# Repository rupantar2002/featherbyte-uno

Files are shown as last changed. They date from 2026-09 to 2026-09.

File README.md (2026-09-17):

<div align="center">
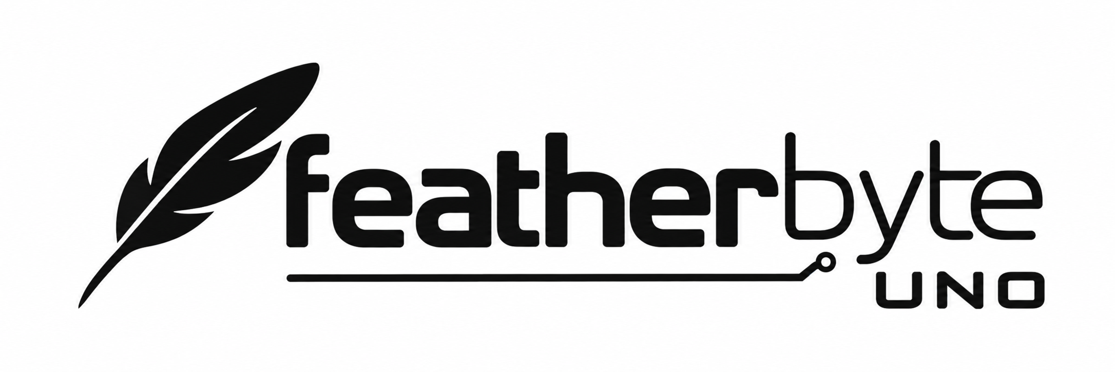
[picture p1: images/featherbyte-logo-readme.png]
Featherbyte Uno logo
  

  # Featherbyte Uno

  **A RISC-V development board in the Arduino Uno footprint.**

  USB-C • Arduino-compatible headers • CAN • Open hardware

  [Hardware](#hardware) · [References](#reference-documents) · [Getting started](#getting-started) · [Manufacturing](#manufacturing) · [Project status](#project-status)
</div>

<p align="center">
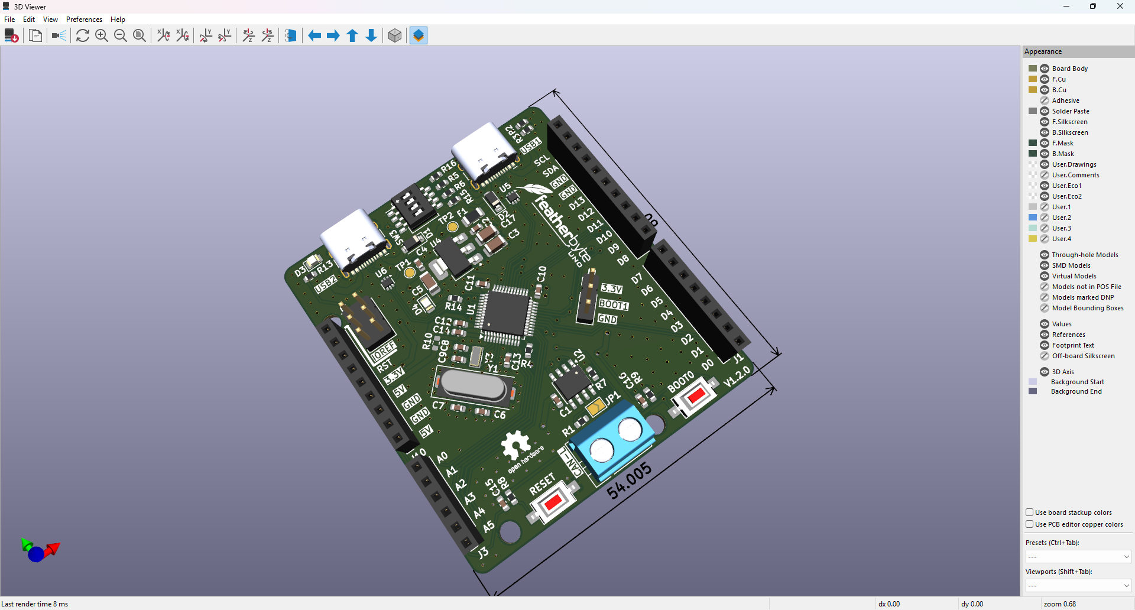
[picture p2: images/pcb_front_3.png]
Featherbyte Uno front 3D render
  
</p>

Featherbyte Uno brings the WCH **CH32V203** RISC-V microcontroller to the familiar Arduino Uno form factor. It is designed for projects that want the practical shield ecosystem, generous headers, modern USB-C connectivity, and a hardware CAN interface in one open, inspectable board design.

> [!WARNING]
> This is an active hardware project, not yet a production-qualified board. Review the design files and validate the board for your use case before ordering or deploying hardware.

## Capabilities

| | Featherbyte Uno provides |
| --- | --- |
| **Compute** | WCH CH32V203CxT6, a 32-bit RISC-V MCU based on WCH's QingKe V4B core |
| **Form factor** | Arduino Uno–compatible header layout, board outline, and mounting pattern |
| **USB** | Two USB-C receptacles: a USB device/power-input connection and a USB host + device/power-input connection |
| **Field bus** | On-board TJA1050 high-speed CAN transceiver with a screw terminal for CANH/CANL |
| **Debug** | Dedicated SWD programming/debug header |
| **Boot control** | BOOT0 push button and BOOT1 selection jumper |
| **Power & protection** | 5 V and 3.3 V header rails, USB protection, and labelled power connections |
| **Design source** | Native KiCad schematic, PCB, symbols, footprints, 3D models, and Gerbers |

## Hardware

<p align="center">
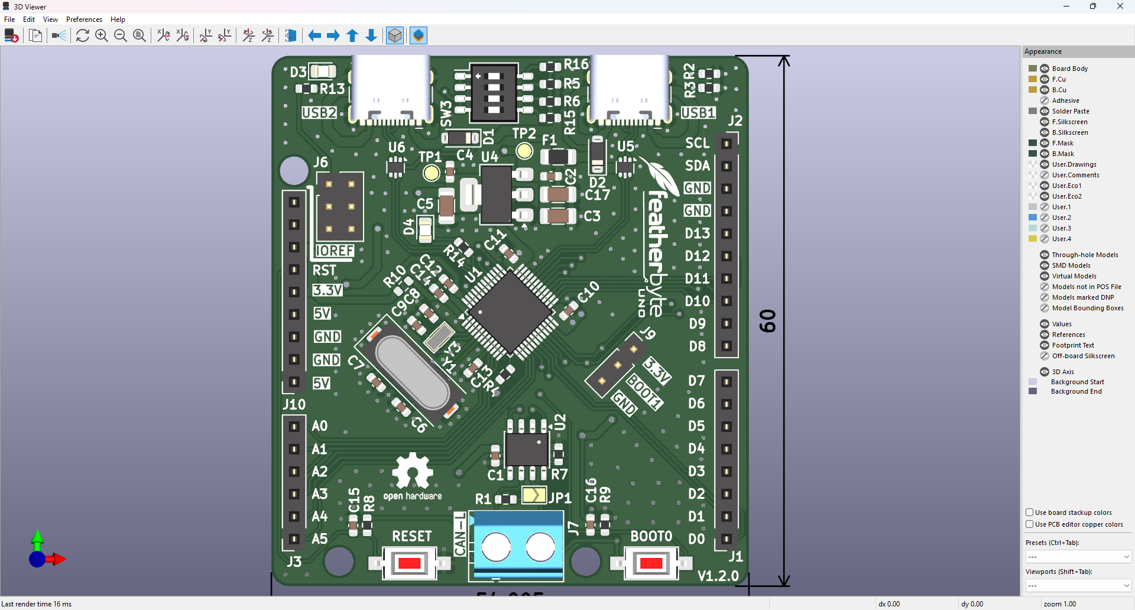
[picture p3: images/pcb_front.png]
Featherbyte Uno top-side board render
  
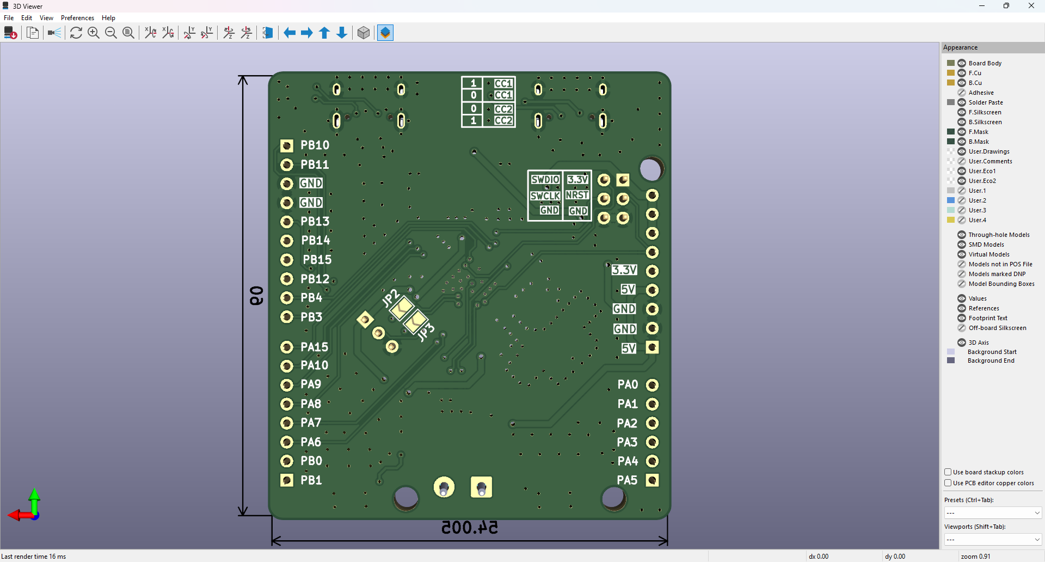
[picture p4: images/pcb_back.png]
Featherbyte Uno bottom-side board render
  
</p>

The board preserves the recognizable Uno layout while exposing CH32V203 GPIO on the standard-style digital and analog header positions. The front side carries both USB-C connections, the MCU, boot/reset controls, CAN terminal, and the Arduino-compatible headers. The reverse side provides a clearly labelled SWD header and additional breakout access.

### Key interfaces

| Interface | What it is for |
| --- | --- |
| **USB1 / USB-C device** | Device-mode connection and power input |
| **USB2 / USB-C host + device** | USB host/device connection and power input |
| **CAN** | High-speed CAN through the TJA1050 transceiver and CANH/CANL terminal |
| **SWD** | SWDIO, SWCLK, NRST, 3.3 V, and GND for programming and debugging |
| **Arduino headers** | Digital, analog, power, I²C, and SPI-style expansion in the Uno form factor |

<p align="center">
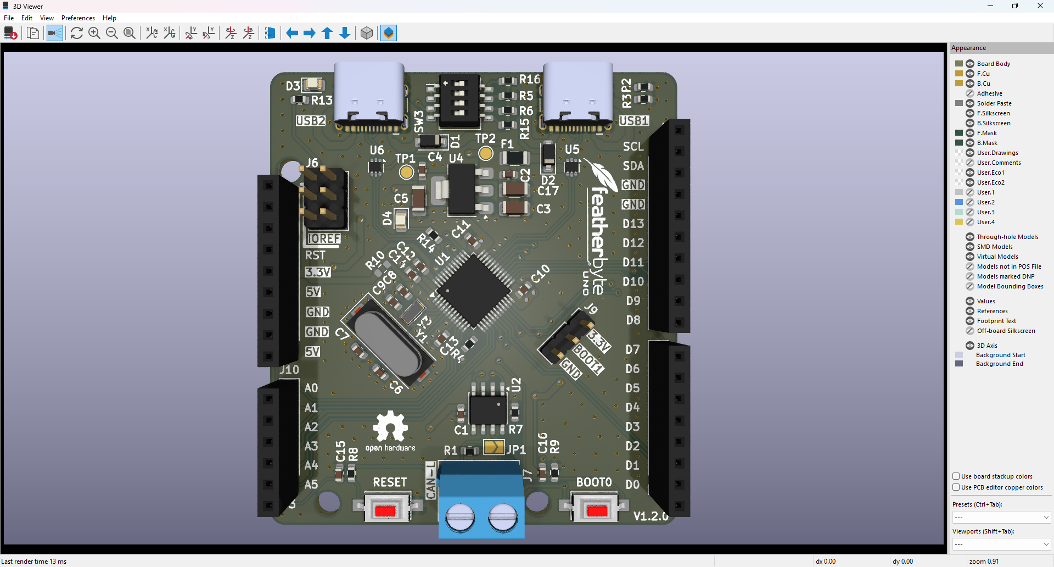
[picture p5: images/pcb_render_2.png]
Featherbyte Uno rear 3D render showing SWD breakout
  
</p>

## Hardware validation

<p align="center">
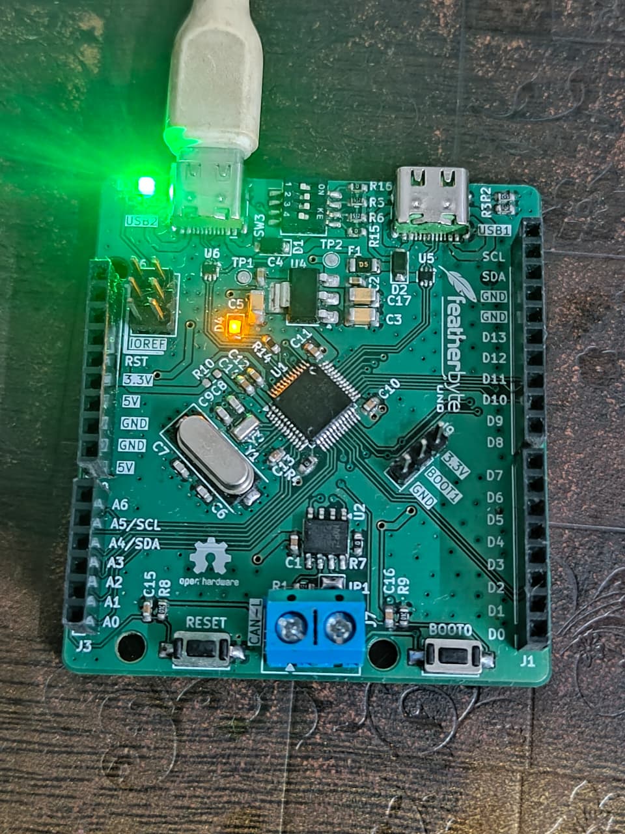
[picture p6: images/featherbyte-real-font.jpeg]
Assembled Featherbyte Uno prototype powered over USB
  
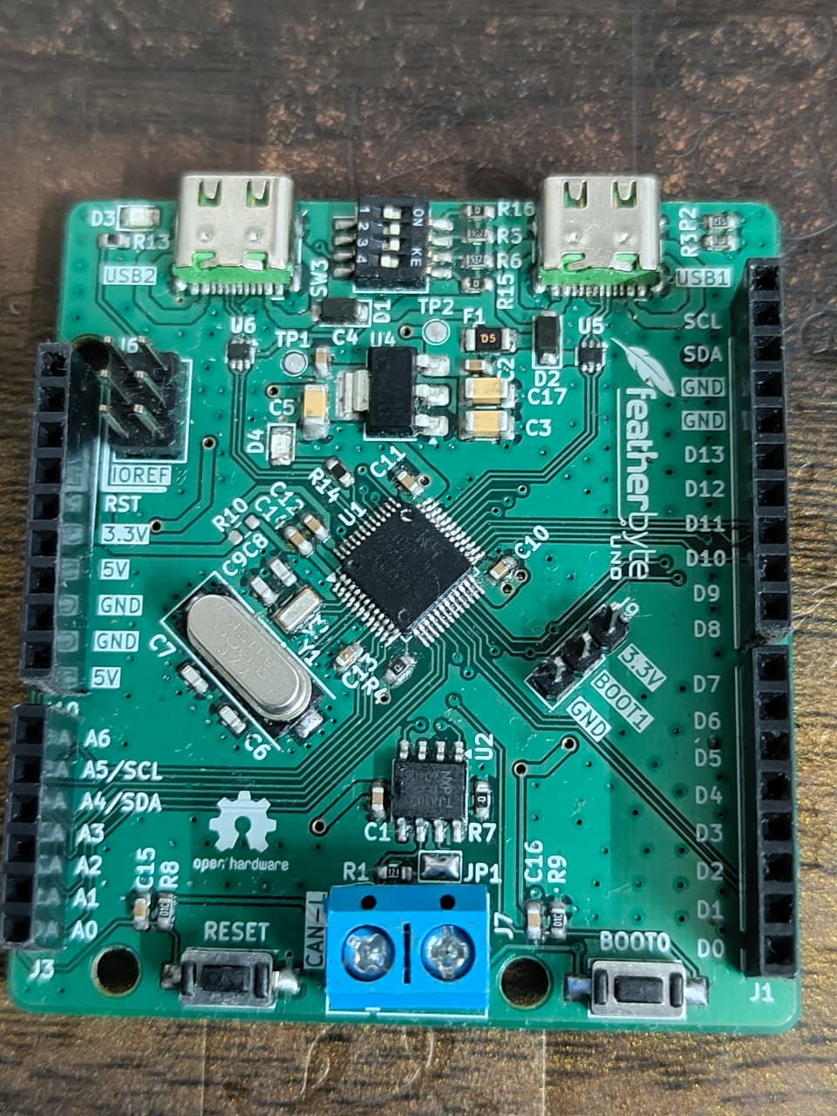
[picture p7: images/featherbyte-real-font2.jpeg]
Assembled Featherbyte Uno prototype front view
  
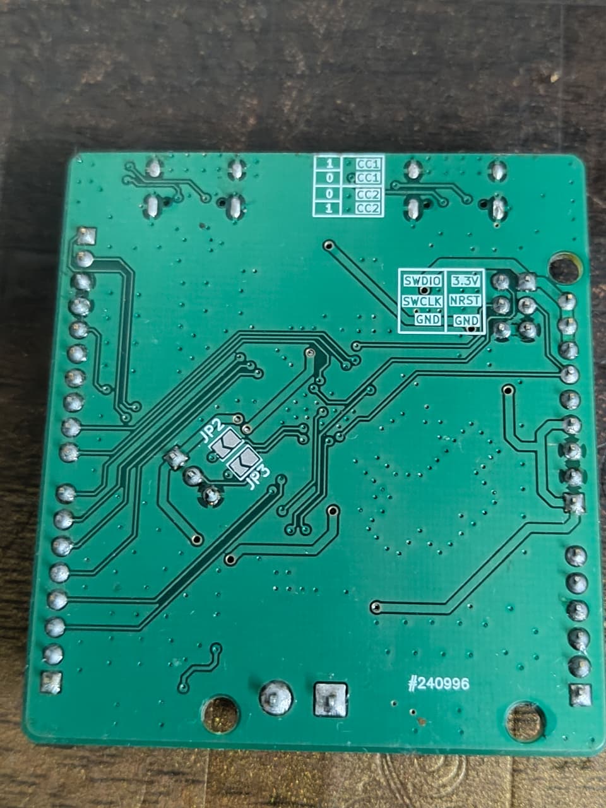
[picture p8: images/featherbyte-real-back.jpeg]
Assembled Featherbyte Uno prototype rear view
  
</p>

The images above show an assembled Featherbyte Uno prototype on the bench.

> [!CAUTION]
> These photographs show an **early board revision**. The current KiCad project includes silkscreen corrections and additions that are not reflected on this prototype. Treat the checked-in design files as the source of truth for the current revision.

### Blink test on real hardware

<p align="center">
  Blink test running on an assembled Featherbyte Uno prototype
</p>

*A blink test running on the assembled prototype. This demonstrates basic firmware execution on real hardware; it does not constitute full board validation.*

## Repository map

```text
.
├── hardware/
│   └── featherbyte-uno-v1.0.0/
│       ├── featherbyte-uno-v1.0.0.kicad_pro  # KiCad project
│       ├── featherbyte-uno-v1.0.0.kicad_sch  # schematic
│       ├── featherbyte-uno-v1.0.0.kicad_pcb  # PCB layout
│       ├── Gerber/                           # fabrication outputs
│       ├── 3d/                               # component STEP models
│       ├── footprints/                       # custom footprints
│       └── sym/                              # project symbol libraries
├── docs/                                     # schematic and component references
└── images/                                   # board renders used here
```

## Reference documents

The documents below are checked into the repository for offline design review and bring-up.

| Document | Purpose |
| --- | --- |
| [Featherbyte Uno schematics v1.2.0](docs/schematics-v1.2.0.pdf) | Current schematic reference export |
| [CH32V203 datasheet](docs/CH32V203DS0.PDF) | MCU electrical characteristics, pin functions, and package details |
| [CH32FV2x / V3x reference manual](docs/CH32FV2x_V3xRM.PDF) | MCU peripherals, registers, and programming reference |
| [QingKe V4 processor manual](docs/QingKeV4_Processor_Manual.PDF) | RISC-V core architecture and instruction-set reference |
| [TJA1050 datasheet](docs/TJA1050.pdf) | High-speed CAN transceiver reference |

## Getting started

### Explore or modify the board

1. Install [KiCad](https://www.kicad.org/download/).
2. Clone this repository.
3. Open [`hardware/featherbyte-uno-v1.0.0/featherbyte-uno-v1.0.0.kicad_pro`](hardware/featherbyte-uno-v1.0.0/featherbyte-uno-v1.0.0.kicad_pro) in KiCad.
4. Use the schematic and PCB editors to inspect the design; the project-local symbol, footprint, and 3D-model assets are included.

### Program and debug

The board exposes an SWD header labelled **SWDIO**, **SWCLK**, **NRST**, **3.3V**, and **GND**. Connect a compatible 3.3 V SWD debugger to this header. Firmware, toolchain, bootloader, and flashing instructions are not yet included in this repository—please treat bring-up as development work until those are published.

## Manufacturing

Ready-to-export fabrication files are in [`hardware/featherbyte-uno-v1.0.0/Gerber`](hardware/featherbyte-uno-v1.0.0/Gerber). Before submitting an order:

1. Check the Gerbers and drill files in your fabricator’s viewer.
2. Confirm stack-up, finish, thickness, and assembly constraints against your requirements.
3. Independently verify the schematic, PCB revision, and component availability.
4. Bring up and test a small batch before any larger build.

The included hardware project identifies the current schematic revision as **v1.2.0**. The directory name is retained as `featherbyte-uno-v1.0.0` to match the checked-in project and fabrication paths.

## Project status

| Area | Status |
| --- | --- |
| KiCad source | Available |
| Gerber fabrication outputs | Available |
| PCB renders | Available |
| Firmware and examples | Not yet published here |
| BOM / assembly documentation | Not yet published here |
| License | [MIT License](LICENSE) |

## Contributing

Design review, testing notes, issues, and pull requests are welcome. For hardware changes, please include the relevant KiCad source changes and describe any electrical, mechanical, or manufacturing impact.

## License

[MIT License](LICENSE)

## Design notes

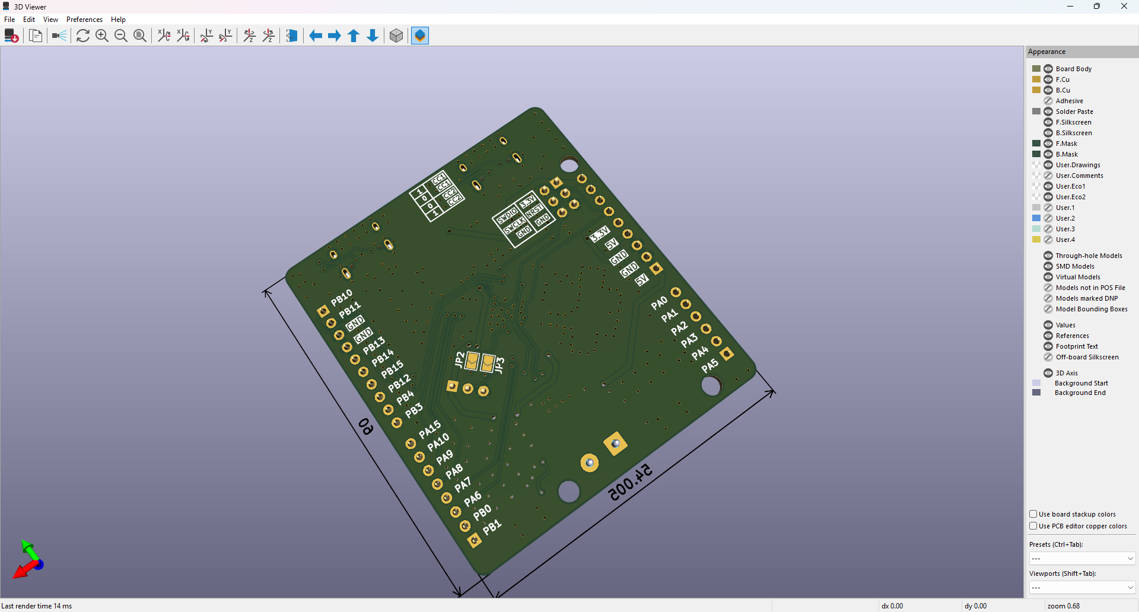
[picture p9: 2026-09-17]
images/pcb_back_2.png

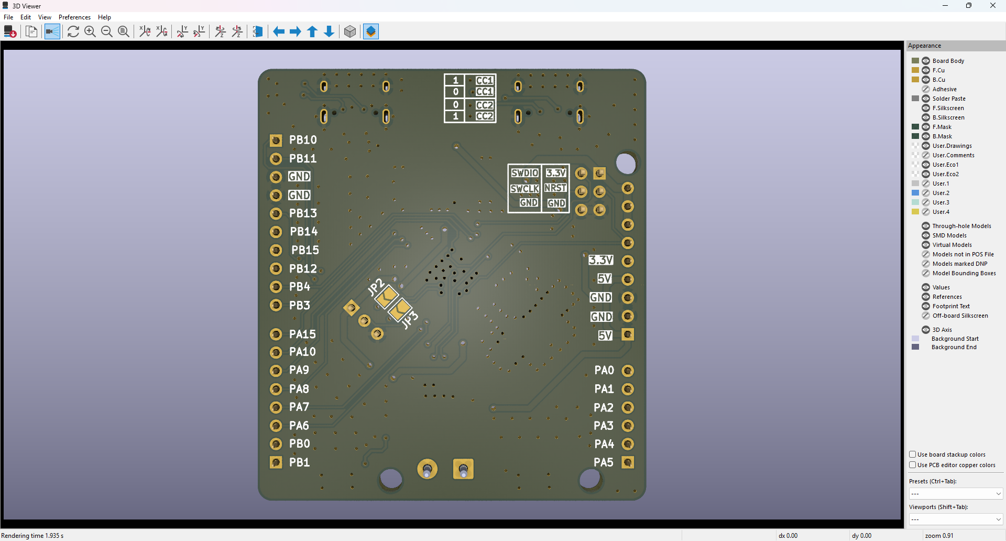
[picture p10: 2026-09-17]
images/pcb_render_1.png

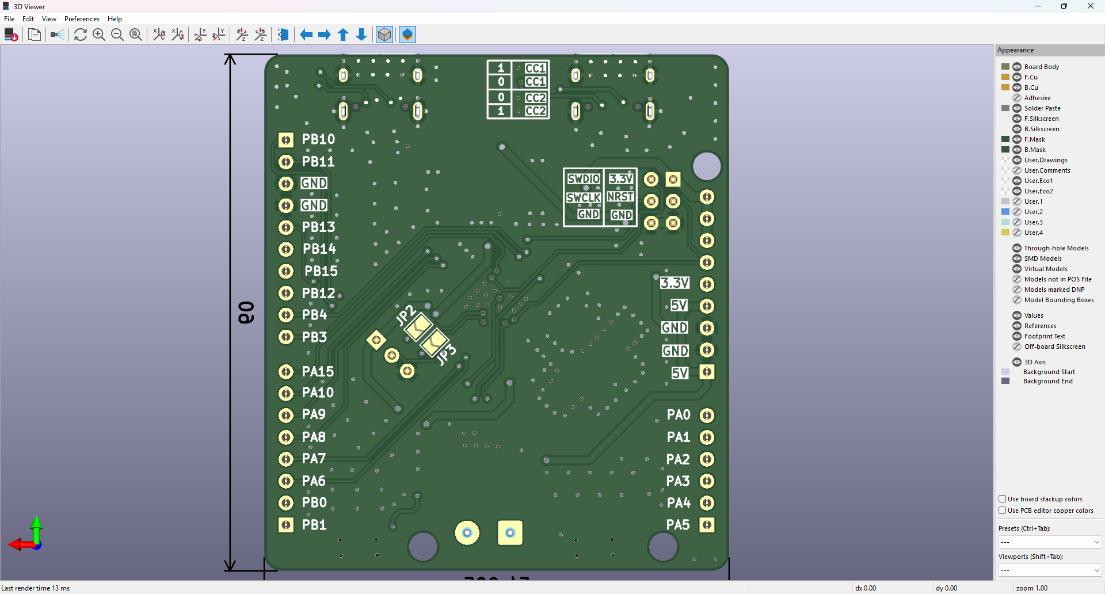
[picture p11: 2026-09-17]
images/pcb_back_3.png

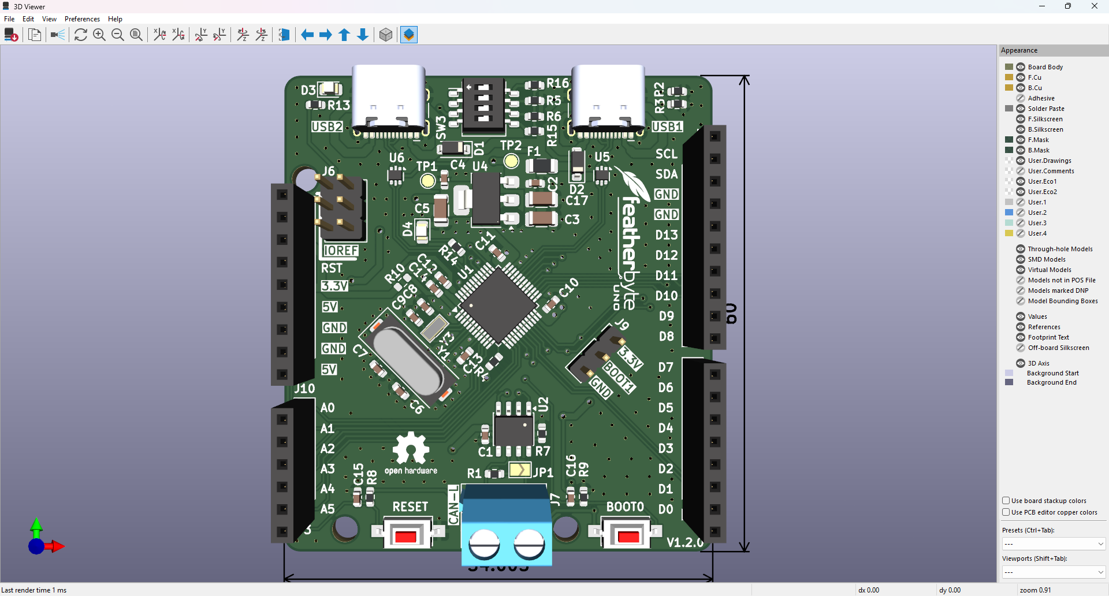
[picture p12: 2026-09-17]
images/pcb_front_2.png

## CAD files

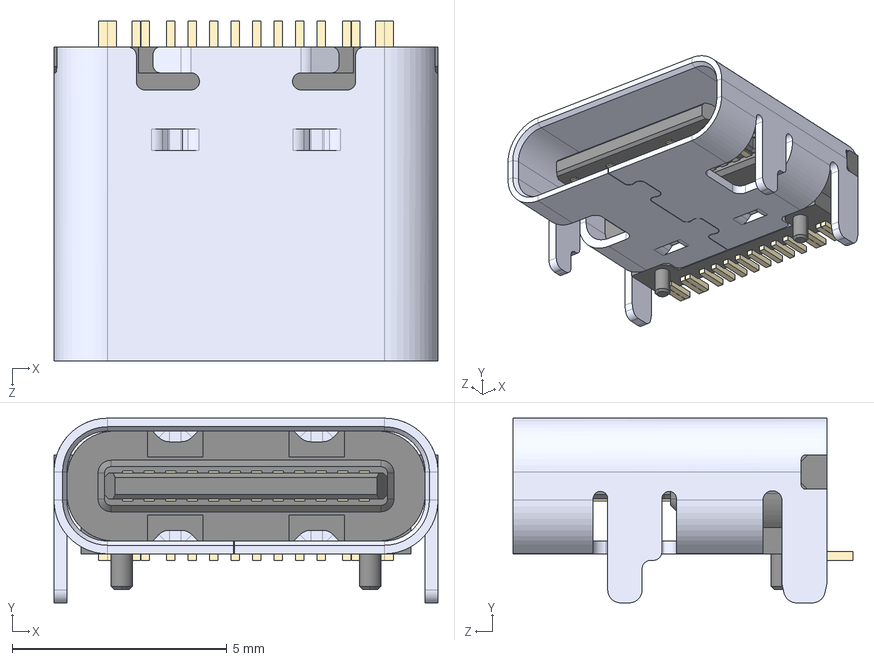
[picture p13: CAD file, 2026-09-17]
hardware/featherbyte-uno-v1.0.0/3d/TYPE-C-31-M-12--3DModel-STEP-56544.STEP
8.94 x 4.30 x 7.90 mm

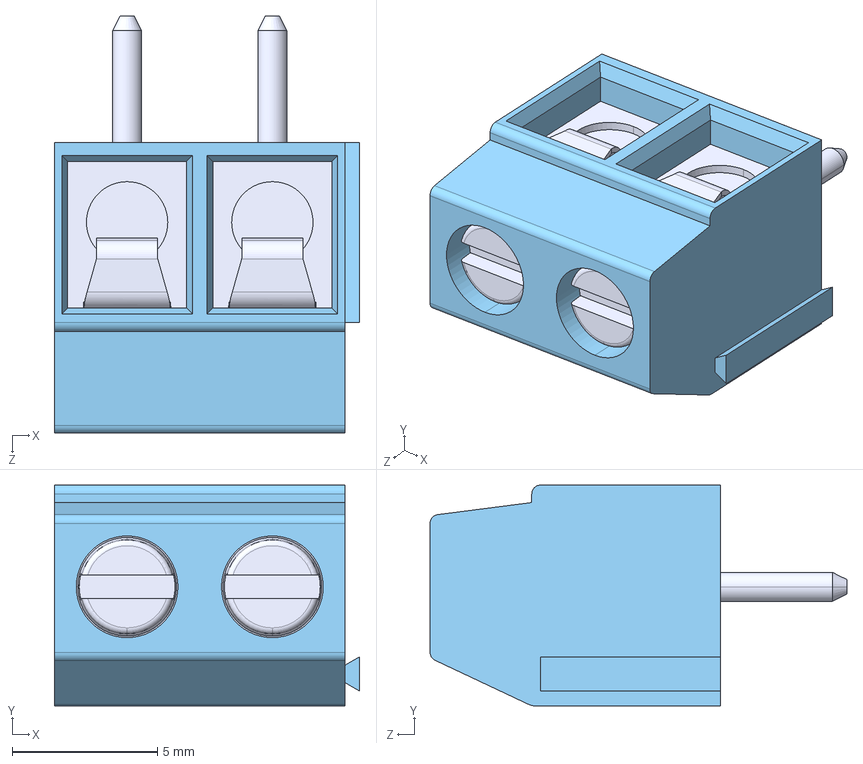
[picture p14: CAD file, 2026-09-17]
hardware/featherbyte-uno-v1.0.0/3d/Same_Sky_TB002-500-02BE.step
10.5 x 7.60 x 14.4 mm

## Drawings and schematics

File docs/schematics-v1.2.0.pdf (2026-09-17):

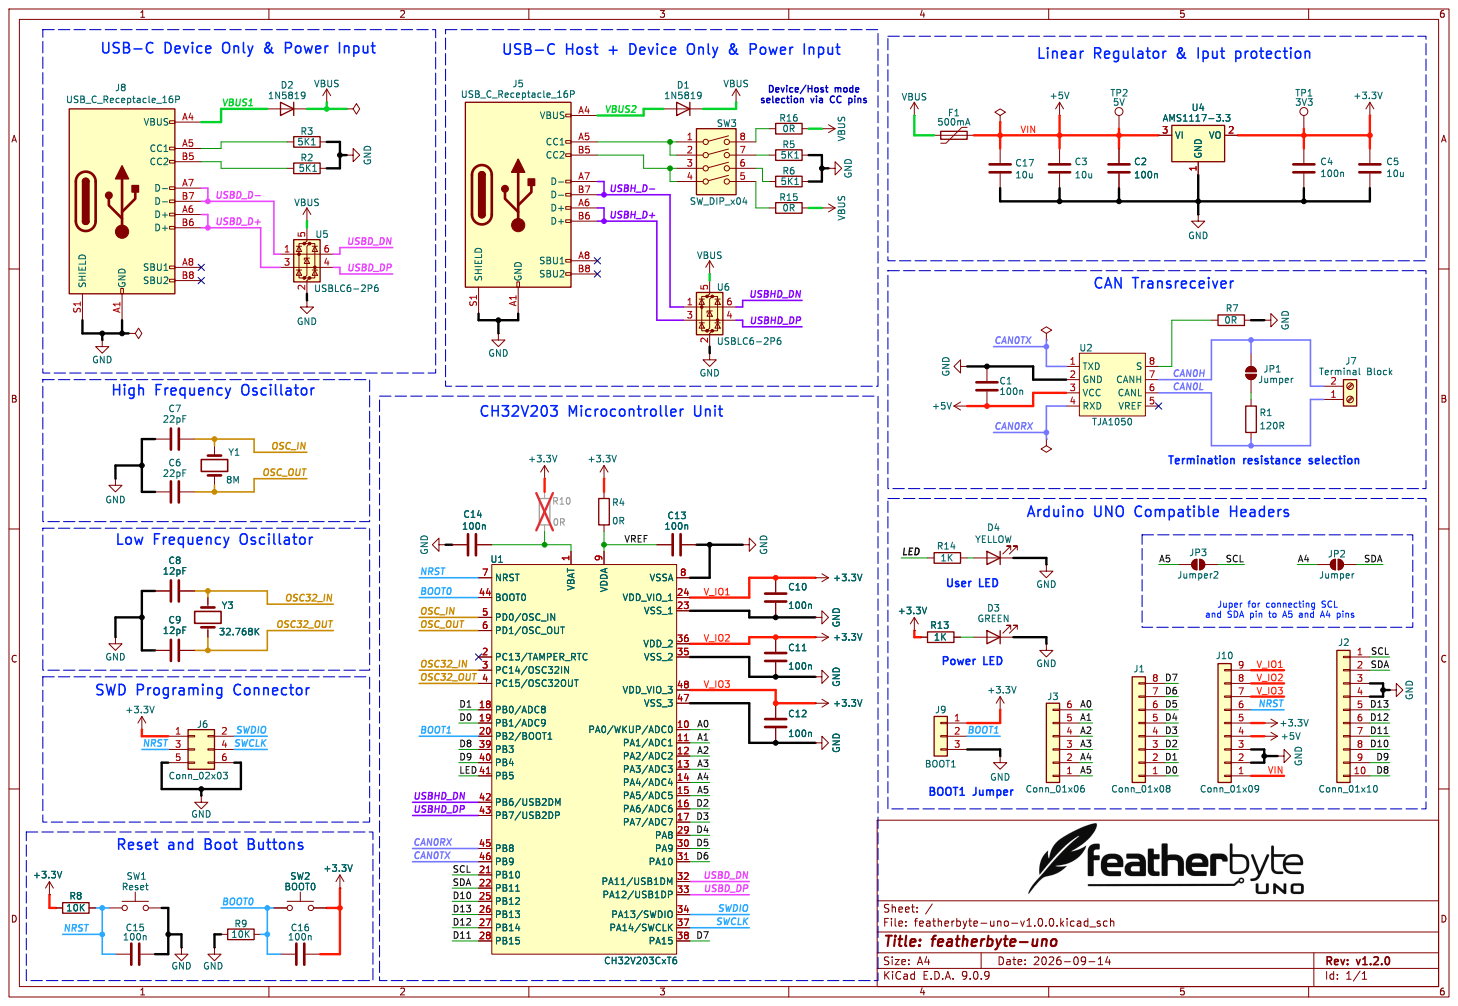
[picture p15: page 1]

USB-C Device Only & Power Input
4 U5 USBLC6-2P6 R2

USB-C Host + Device Only & Power Input

and SDA pin to A5 and A4 pins Linear Regulator & Iput protection
100n GND GND

selection via CC pins

9 VSSA 8 VDD_VIO_1 24 VSS_1 23 VDD_2 36 VSS_2 35 VDD_VIO_3 48 VSS_3 47 PA0/WKUP/ADC0 10 PA1/ADC1 11 PA2/ADC2 12 PA3/ADC3 13 PA4/ADC4 14 PA5/ADC5 15 PA6/ADC6 16 PA7/ADC7 17 PA8 29 PA9 30 PA10 31 PA11/USB1DM 32 PA12/USB1DP 33 PA13/SWDIO 34 PA14/SWCLK 37 PA15 38 +3.3V +3.3V

9 VSSA 8 VDD_VIO_1 24 VSS_1 23 VDD_2 36 VSS_2 35 VDD_VIO_3 48 VSS_3 47 PA0/WKUP/ADC0 10 PA1/ADC1 11 PA2/ADC2 12 PA3/ADC3 13 PA4/ADC4 14 PA5/ADC5 15 PA6/ADC6 16 PA7/ADC7 17 PA8 29 PA9 30 PA10 31 PA11/USB1DM 32 PA12/USB1DP 33 PA13/SWDIO 34 PA14/SWCLK 37 PA15 38 U1 CH32V203CxT6 R13

Reset and Boot Buttons
SW1 Reset C15

Id: 1/1 Title: featherbyte-uno

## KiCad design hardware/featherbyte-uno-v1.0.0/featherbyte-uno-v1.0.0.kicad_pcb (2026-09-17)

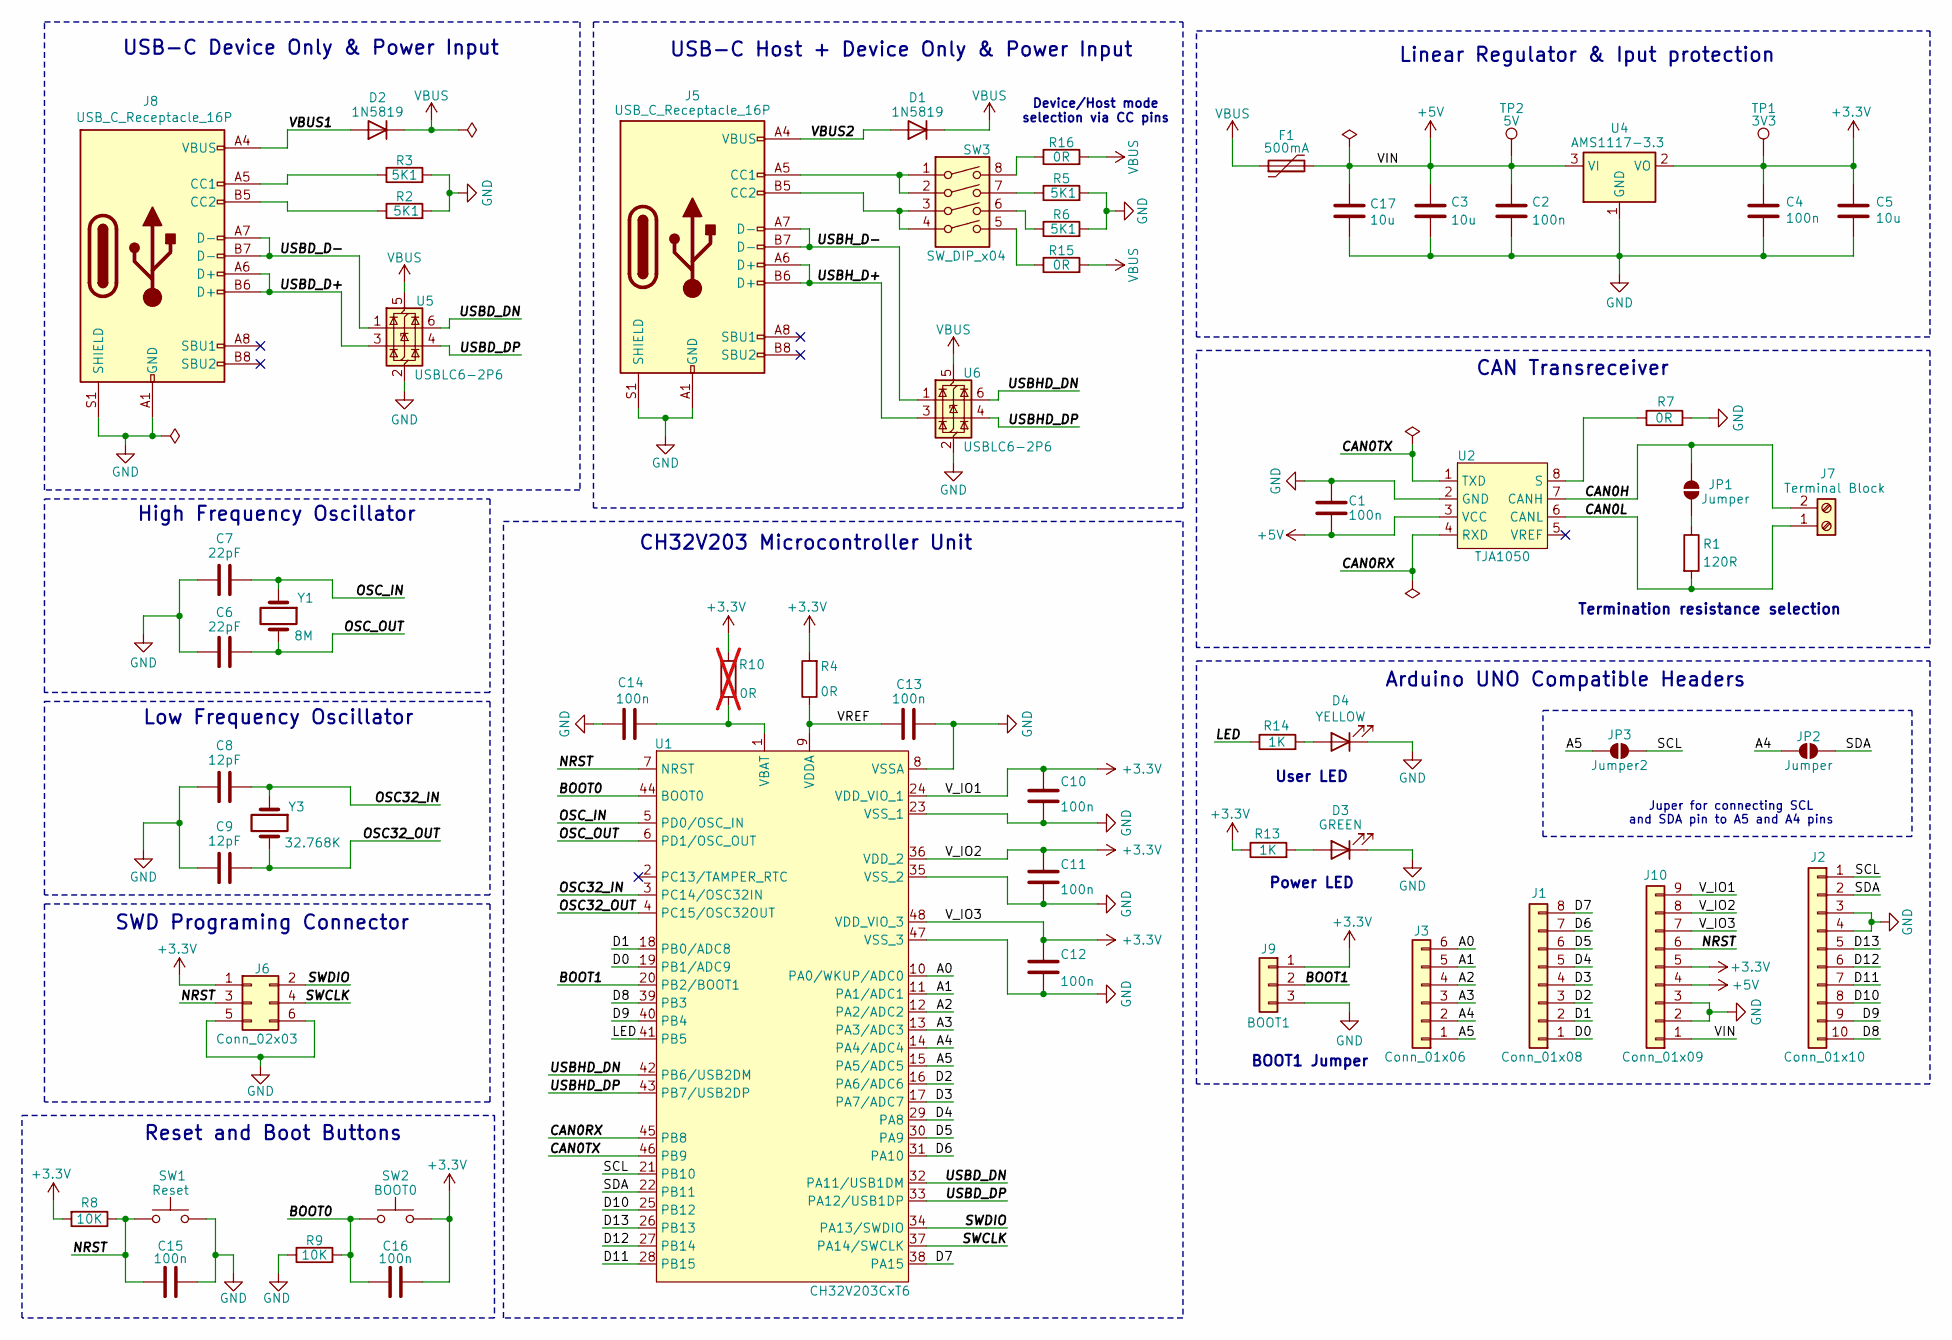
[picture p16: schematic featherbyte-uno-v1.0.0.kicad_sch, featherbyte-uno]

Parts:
C1, C2, C4, C10, C11, C12, C13, C14, C15, C16: 100n; C_0603_1608Metric
C3, C5, C17: 10u; C_1206_3216Metric
C6, C7: 22pF; C_0603_1608Metric
C8, C9: 12pF; C_0603_1608Metric
D1, D2: 1N5819; D_SOD-123
D3: GREEN; LED_0805_2012Metric
D4: YELLOW; LED_0805_2012Metric
F1: 500mA; Fuse_1206_3216Metric
J1: Conn_01x08; PinSocket_1x08_P2.54mm_Vertical
J2: Conn_01x10; PinSocket_1x10_P2.54mm_Vertical
J3: Conn_01x06; PinSocket_1x06_P2.54mm_Vertical
J5, J8: USB_C_Receptacle_16P; USB_C_Receptacle_HCTL_HC-TYPE-C-16P-01A
J6: Conn_02x03; PinHeader_2x03_P2.54mm_Vertical
J7: Terminal Block; TerminalBlock_MaiXu_MX126-5.0-02P_1x02_P5.00mm
J9: BOOT1; PinHeader_1x03_P2.54mm_Vertical
J10: Conn_01x09; PinSocket_1x09_P2.54mm_Vertical
JP1, JP2: Jumper; SolderJumper-2_P1.3mm_Open_TrianglePad1.0x1.5mm
JP3: Jumper2; SolderJumper-2_P1.3mm_Open_TrianglePad1.0x1.5mm
R1: 120R; R_0603_1608Metric
R2, R3, R5, R6: 5K1; R_0603_1608Metric
R4, R7, R15, R16: 0R; R_0603_1608Metric
R8, R9: 10K; R_0603_1608Metric
R10: 0R; R_0603_1608Metric; not fitted
R13, R14: 1K; R_0603_1608Metric
SW1: Reset; SW_SPST_CK_RS282G05A3
SW2: BOOT0; SW_SPST_CK_RS282G05A3
SW3: SW_DIP_x04; SW_DIP_SPSTx04_Slide_KingTek_DSHP04TS_W7.62mm_P1.27mm
TP1: 3V3; TestPoint_Pad_D1.5mm
TP2: 5V; TestPoint_Pad_D1.5mm
U1: CH32V203CxT6; LQFP-48_7x7mm_P0.5mm
U2: TJA1050; SO-8_3.9x4.9mm_P1.27mm
U4: AMS1117-3.3; SOT-223-3_TabPin2
U5, U6: USBLC6-2P6; SOT-666
Y1: 8M; Crystal_SMD_HC49-SD
Y3: 32.768K; Crystal_SMD_3215-2Pin_3.2x1.5mm

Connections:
+3.3V: C4.1, C5.1, C10.1, C11.1, C12.1, C16.2, J6.1, J9.1, J10.5, J10.7, J10.8, J10.9, R4.2, R8.2, R10.2, R13.1, SW2.2, TP1.1, U1.24 (VDD_VIO_1), U1.36 (VDD_2), U1.48 (VDD_VIO_3), U4.2 (VO)
+5V: C1.2, C2.1, C3.1, C17.1, F1.2, J10.1, J10.4, TP2.1, U2.3 (VCC), U4.3 (VI)
/A0: J3.6, U1.10 (PA0/WKUP/ADC0)
/A1: J3.5, U1.11 (PA1/ADC1)
/A2: J3.4, U1.12 (PA2/ADC2)
/A3: J3.3, U1.13 (PA3/ADC3)
/A4: J3.2, JP2.1 (A), U1.14 (PA4/ADC4)
/A5: J3.1, JP3.1 (A), U1.15 (PA5/ADC5)
/BOOT0: C16.1, R9.2, SW2.1, U1.44 (BOOT0)
/BOOT1: J9.2, U1.20 (PB2/BOOT1)
/CAN0H: J7.2, JP1.2 (B), U2.7 (CANH)
/CAN0L: J7.1, R1.2, U2.6 (CANL)
/CAN0RX: U1.45 (PB8), U2.4 (RXD)
/CAN0TX: U1.46 (PB9), U2.1 (TXD)
/D0: J1.1, U1.19 (PB1/ADC9)
/D1: J1.2, U1.18 (PB0/ADC8)
/D2: J1.3, U1.16 (PA6/ADC6)
/D3: J1.4, U1.17 (PA7/ADC7)
/D4: J1.5, U1.29 (PA8)
/D5: J1.6, U1.30 (PA9)
/D6: J1.7, U1.31 (PA10)
/D7: J1.8, U1.38 (PA15)
/D8: J2.10, U1.39 (PB3)
/D9: J2.9, U1.40 (PB4)
/D10: J2.8, U1.25 (PB12)
/D11: J2.7, U1.28 (PB15)
/D12: J2.6, U1.27 (PB14)
/D13: J2.5, U1.26 (PB13)
/LED: R14.1, U1.41 (PB5)
/NRST: C15.1, J6.3, J10.6, R8.1, SW1.1, U1.7 (NRST)
/OSC32_IN: C8.1, U1.3 (PC14/OSC32IN), Y3.1
/OSC32_OUT: C9.1, U1.4 (PC15/OSC32OUT), Y3.2
/OSC_IN: C7.1, U1.5 (PD0/OSC_IN), Y1.1
/OSC_OUT: C6.1, U1.6 (PD1/OSC_OUT), Y1.2
/SCL: J2.1, JP3.2 (B), U1.21 (PB10)
/SDA: J2.2, JP2.2 (B), U1.22 (PB11)
/SWCLK: J6.4, U1.37 (PA14/SWCLK)
/SWDIO: J6.2, U1.34 (PA13/SWDIO)
/USBD_D+: J8.A6 (D+), J8.B6 (D+), U5.3 (I/O2)
/USBD_D-: J8.A7 (D-), J8.B7 (D-), U5.1 (I/O1)
/USBD_DN: U1.32 (PA11/USB1DM), U5.6 (I/O1)
/USBD_DP: U1.33 (PA12/USB1DP), U5.4 (I/O2)
/USBHD_DN: U1.42 (PB6/USB2DM), U6.6 (I/O1)
/USBHD_DP: U1.43 (PB7/USB2DP), U6.4 (I/O2)
/USBH_D+: J5.A6 (D+), J5.B6 (D+), U6.3 (I/O2)
/USBH_D-: J5.A7 (D-), J5.B7 (D-), U6.1 (I/O1)
/VBUS1: D2.2 (A), J8.A4 (VBUS), J8.A9 (VBUS), J8.B4 (VBUS), J8.B9 (VBUS)
/VBUS2: D1.2 (A), J5.A4 (VBUS), J5.A9 (VBUS), J5.B4 (VBUS), J5.B9 (VBUS)
/VREF: C13.1, R4.1, U1.9 (VDDA)
GND: C1.1, C2.2, C3.2, C4.2, C5.2, C6.2, C7.2, C8.2, C9.2, C10.2, C11.2, C12.2, C13.2, C14.2, C15.2, C17.2, D3.1 (K), D4.1 (K), J2.3, J2.4, J5.A1 (GND), J5.A12 (GND), J5.B1 (GND), J5.B12 (GND), J5.S1 (SHIELD), J6.5, J6.6, J8.A1 (GND), J8.A12 (GND), J8.B1 (GND), J8.B12 (GND), J8.S1 (SHIELD), J9.3, J10.2, J10.3, R2.2, R3.2, R5.2, R6.2, R7.2, R9.1, SW1.2, U1.8 (VSSA), U1.23 (VSS_1), U1.35 (VSS_2), U1.47 (VSS_3), U2.2 (GND), U4.1 (GND), U5.2 (GND), U6.2 (GND)
unnamed: D3.2 (A), R13.2
unnamed: D4.2 (A), R14.2
unnamed: J5.A5 (CC1), SW3.1, SW3.2
unnamed: J5.B5 (CC2), SW3.3, SW3.4
unnamed: J8.A5 (CC1), R3.1
unnamed: J8.B5 (CC2), R2.1
unnamed: JP1.1 (A), R1.1
unnamed: R5.1, SW3.7
unnamed: R6.1, SW3.6
unnamed: R15.1, SW3.5
unnamed: R16.1, SW3.8
unnamed: C14.1, R10.1, U1.1 (VBAT)
unnamed: R7.1, U2.8 (S)
VBUS: D1.1 (K), D2.1 (K), F1.1, R15.2, R16.2, U5.5 (VBUS), U6.5 (VBUS)

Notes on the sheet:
Juper for connecting SCL and SDA pin to A5 and A4 pins
USB-C Device Only & Power Input
Termination resistance selection
SWD Programing Connector
BOOT1 Jumper
High Frequency Oscillator
Linear Regulator & Iput protection
Reset and Boot Buttons
Low Frequency Oscillator
Arduino UNO Compatible Headers
Power LED
CAN Transreceiver
USB-C Host + Device Only & Power Input
User LED
Device/Host mode selection via CC pins
CH32V203 Microcontroller Unit

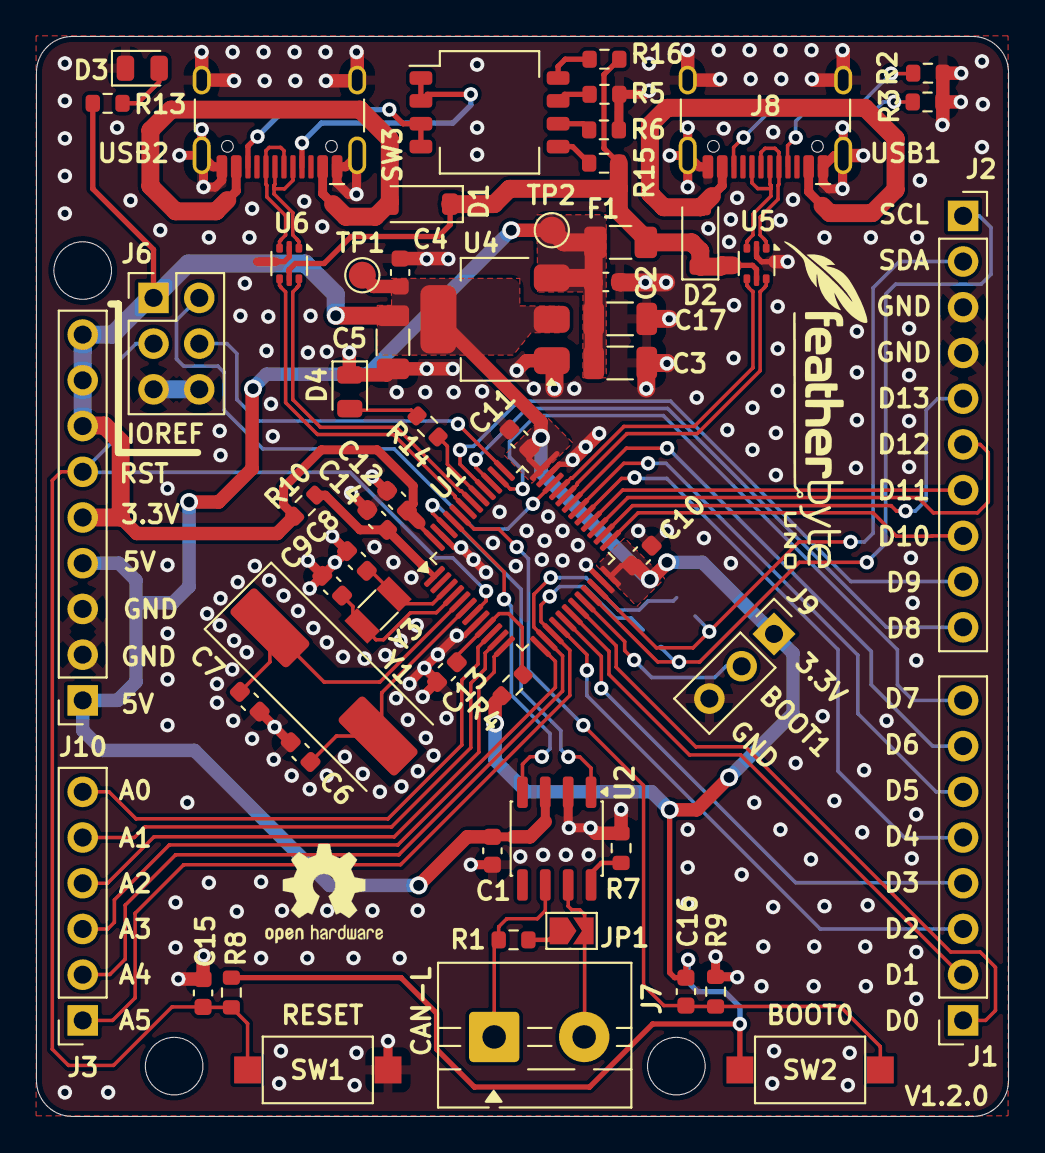
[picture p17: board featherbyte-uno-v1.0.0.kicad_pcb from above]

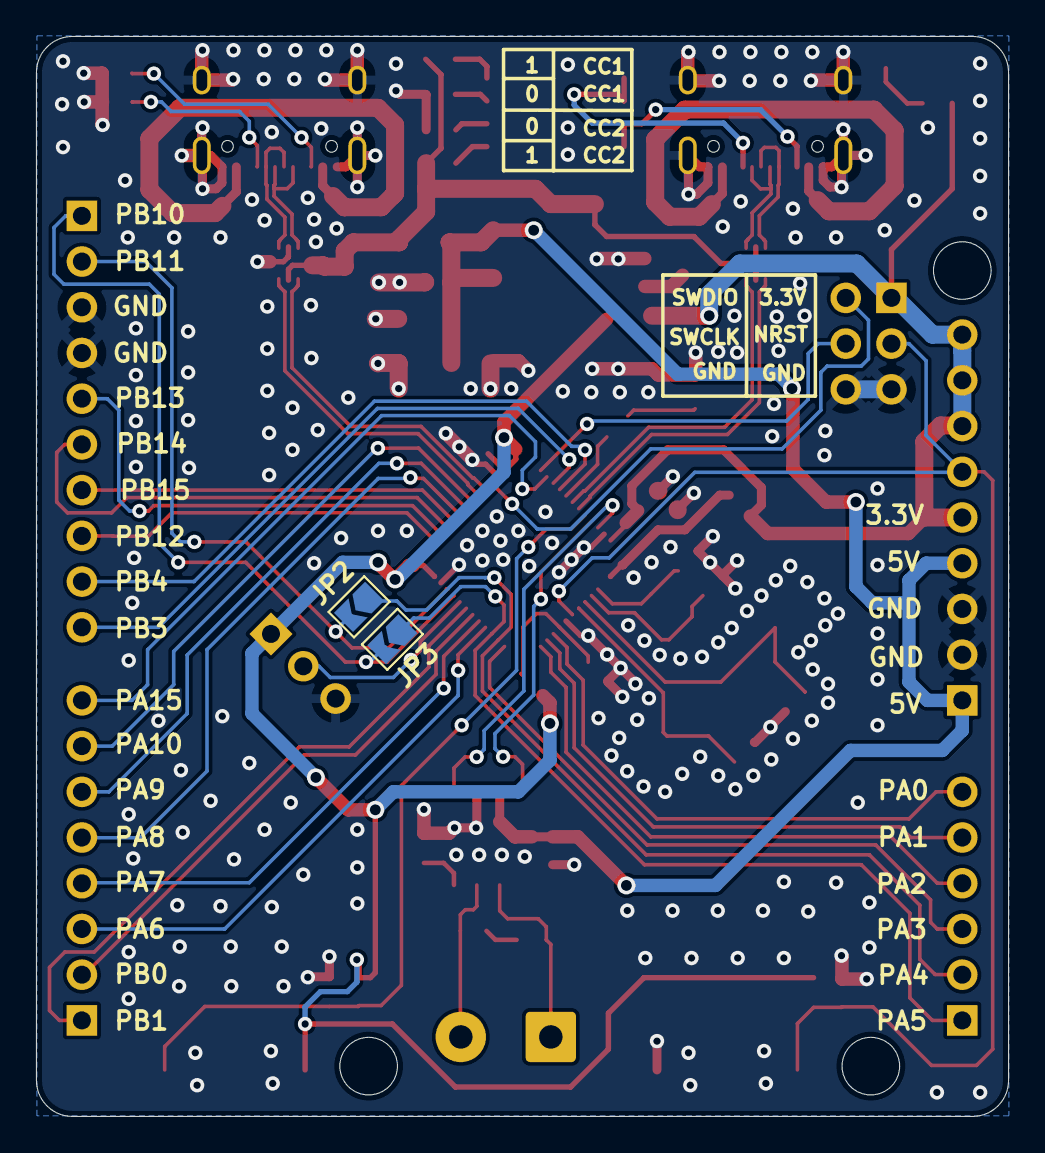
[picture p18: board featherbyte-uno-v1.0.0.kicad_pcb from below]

Board: 2 copper layers, 54.0 x 60.0 mm, 60 parts (2 on the bottom side), 64 nets.

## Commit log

2026-08-26 kicad project added
    [featherbyte-uno-v1.0.0.kicad_pcb, featherbyte-uno-v1.0.0.kicad_sch]
2026-08-27 canbus, and programing circuitry added
    [featherbyte-uno-v1.0.0.kicad_sch]
2026-08-29 schematics ready for layout
    [featherbyte-uno-v1.0.0.kicad_sch]
2026-08-29 footprint asignment complete
    [featherbyte-uno-v1.0.0.kicad_sch]
2026-08-29 pin headers,mounting holes and board outline has been defined
    [featherbyte-uno-v1.0.0.kicad_pcb]
2026-08-30 usb tvs diode orientation changed
    [featherbyte-uno-v1.0.0.kicad_sch]
2026-08-30 type c port and screw terminal 3d models added
    [Same_Sky_TB002-500-02BE.step, TYPE-C-31-M-12--3DModel-STEP-56544.STEP]
2026-08-30 can bus connector pins reversed
    [featherbyte-uno-v1.0.0.kicad_sch]
2026-08-30 components are roughly placed on pcb
    [featherbyte-uno-v1.0.0.kicad_pcb]
2026-08-30 pcb routing ongoing
    [featherbyte-uno-v1.0.0.kicad_pcb, featherbyte-uno-v1.0.0.kicad_sch]
2026-08-31 restarted routing and positioning process
    [featherbyte-uno-v1.0.0.kicad_pcb, featherbyte-uno-v1.0.0.kicad_sch]
2026-08-31 footprints are roughly placed
    [featherbyte-uno-v1.0.0.kicad_pcb]
2026-09-01 pin arrangement changes required
    [featherbyte-uno-v1.0.0.kicad_pcb, featherbyte-uno-v1.0.0.kicad_sch]
2026-09-01 routing process ongoing
    [featherbyte-uno-v1.0.0.kicad_pcb, featherbyte-uno-v1.0.0.kicad_sch]
2026-09-02 all pins routed
    [featherbyte-uno-v1.0.0.kicad_pcb, featherbyte-uno-v1.0.0.kicad_sch]
2026-09-04 all routing done
    [featherbyte-uno-v1.0.0.kicad_pcb, featherbyte-uno-v1.0.0.kicad_sch]
2026-09-05 drc check process ongoing
    [featherbyte-uno-v1.0.0.kicad_pcb, featherbyte-uno-v1.0.0.kicad_sch]
2026-09-05 pin labeling and drc checks has been done
    [featherbyte-uno-v1.0.0.kicad_pcb, featherbyte-uno-v1.0.0.kicad_sch]
2026-09-06 pcb ready
    [featherbyte-uno-v1.0.0.kicad_pcb]
2026-09-06 gerber files added
    [featherbyte-uno-v1.0.0-B_Cu.gbr, featherbyte-uno-v1.0.0-B_Mask.gbr, featherbyte-uno-v1.0.0-B_Paste.gbr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]
2026-09-07 version info addition and adc pin correction done
    [featherbyte-uno-v1.0.0.kicad_pcb, featherbyte-uno-v1.0.0.kicad_sch]
2026-09-07 gerber updated
    [featherbyte-uno-v1.0.0-B_Cu.gbr, featherbyte-uno-v1.0.0-B_Mask.gbr, featherbyte-uno-v1.0.0-B_Paste.gbr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]
2026-09-07 symbols and footprints organised in specific folders
2026-09-09 schematics updated for visual reasons
    [featherbyte-uno-v1.0.0.kicad_sch]
2026-09-14 actual mcu pin names added to back silk screen layer
    [featherbyte-uno-v1.0.0-B_Cu.gbr, featherbyte-uno-v1.0.0-B_Mask.gbr, featherbyte-uno-v1.0.0-B_Paste.gbr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]
2026-09-17 added schematics ploating directory
